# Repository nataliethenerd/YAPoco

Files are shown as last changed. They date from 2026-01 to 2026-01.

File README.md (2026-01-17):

# Yet Another Pocket Color (YAP)
mainimage

> Poco = Pocket Color. This project allows you to put a Game Boy Color in a Game Boy pocket shell. Full pocket colour PCB using the original parts. This board is made with modern screen kits in mind meaning it does not have the voltage rails for the original screen.

**ORDER AT 1MM WITH ENIG**

You can support me on Ko-Fi or by buying the board directly from me [my store](https://nataliethenerd.com/collections/all)

I also occasionally sell pre built PCBs on my store.



## Building

boardview

> [!WARNING]
> I am not responsible for your skill issues!

This board uses all the parts of an original Game Boy Color minus the IR and original screen circuit. Most parts are in the same spot, however if you are having trouble you can check the [interactive BOM](https://nataliethenerd.github.io/yap.html)

The thumbwheel circuit can be connected to an OSD screen to control brightness. The two touch pad wires and be conneced to the pads labelled ↑↓ on the back top left side of the board. The select, A and B pads are easy connection pads for the screen also. 

screenguide

**My recommendations** 

- New power regulator like my [Safer Charge DC](https://nataliethenerd.com/products/safer-charge-dc)
- [Q5 OSD Game Boy Color screen](https://s.click.aliexpress.com/e/_DmvDS95). The OSD allows you to move the screen
- Funny Playing Game Boy Pocket shell, with this shell you wont need to perform any trims.

**New parts**

- [Thumbwheel](https://s.click.aliexpress.com/e/_DFcsKf1)

## Update log:

Feb25: added pinouts for battery and 5V for testing and also my Safer Charger battery indicator LED board. Fixed some shielding pins, tied them to ground.

Jan26: changed the CPU footprint to be a bit more forgiving

| Before | After |
| --- | ----- |
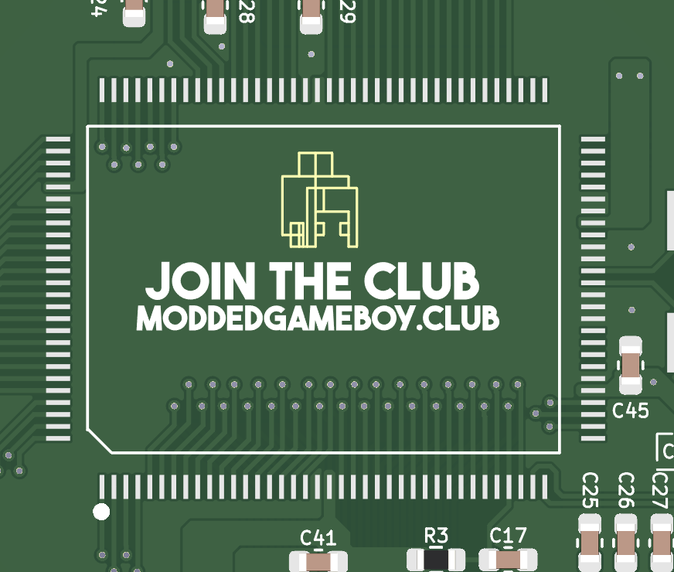
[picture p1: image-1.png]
old footprint
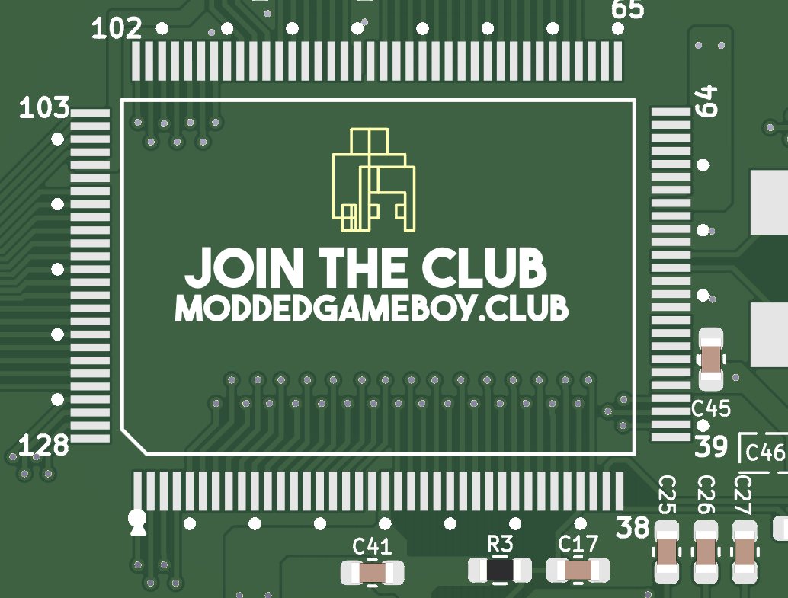
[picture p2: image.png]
new footprint
| |  |

## Thanks
- Hozy for the original Pocket Color concept
- Console and Casks for the thumbwheel circuit

## Follow me

If you are into Game Boy modding or retro gaming, please consider using code "NatalieTheNerd" at:

• [Retro Modding](http://RetroModding.com) 

• [Retro Game Repair Shop](http://RetroGameRepairShop.com) 

• [Extreme Rate](http://ExtremeRate.com)

**My socials**

• [Twitter](https://twitter.com/natalie_thenerd) 

• [Instagram](https://www.instagram.com/natalie.thenerd/) 

• [Modded Gameboy Club](https://moddedgameboy.club/) - a club dedicated to the modification of Game Boys, freely sharing resources

## License

Please do not remove my logo, website and name.



The CC BY-SA 4.0 (Creative Commons Attribution-ShareAlike 4.0 International) license allows you to:

1. **Share** - Copy and redistribute the material in any medium or format.
2. **Adapt** - Remix, transform, and build upon the material for any purpose, even commercially.

### Conditions:

- **Attribution** - You must give appropriate credit, provide a link to the license, and indicate if changes were made. You may do so in any reasonable manner, but not in any way that suggests the licensor endorses you or your use.
- **ShareAlike** - If you remix, transform, or build upon the material, you must distribute your contributions under the same license as the original.

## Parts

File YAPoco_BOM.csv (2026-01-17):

Reference | Value | Footprint | Qty | DNP
BT1 | Battery | CGB:Battery CGB | 1
C1 | 18pF | Capacitor_SMD:C_0603_1608Metric | 1
C2,C48,C49 | 27pF | Capacitor_SMD:C_0603_1608Metric,Resistor_SMD:R_0603_1608Metric | 3
C4 | 22pF | Capacitor_SMD:C_0603_1608Metric | 1
C5,C6,C7 | 100pF | Capacitor_SMD:C_0603_1608Metric | 3
C9,C10,C13,C29,C33,C41,C45 | 10nF | Capacitor_SMD:C_0603_1608Metric | 7
C14,C15,C16 | 47nF | Capacitor_SMD:C_0603_1608Metric | 3
C17,C18,C19,C25,C26,C27,C39 | 1uF | Capacitor_SMD:C_0603_1608Metric | 7
C24,C28,C40,C43,C44 | 100nF | Capacitor_SMD:C_0603_1608Metric | 5
C31 | 4.7uF | Capacitor_SMD:C_0603_1608Metric | 1
C32,C38 | 100uF | Capacitor_SMD:CP_Elec_5x5.3,Capacitor_SMD:CP_Elec_6.3x5.4 | 2
C46 | DNP | Capacitor_SMD:C_0603_1608Metric | 1 | DNP
C47 | 150pF | Capacitor_SMD:C_0603_1608Metric | 1
D2,D5 | 1SS355 | Diode_SMD:D_SOD-323_HandSoldering | 2
D4 | RED | LED_THT:LED_D3.0mm | 1
EM1,EM2,EM3,EM4,EM5,EM9 | BLM11B102S | Resistor_SMD:R_0603_1608Metric | 6
EM6,EM7,EM8 | BLM21PG221SG | Resistor_SMD:R_0805_2012Metric | 3
EM10 | ACM4532-801-2P | Crystal:Crystal_SMD_EuroQuartz_MJ-4Pin_5.0x3.2mm | 1
F1,F2 | ICP-S1.0TN | Fuse:Fuse_1206_3216Metric_Pad1.42x1.75mm_HandSolder | 2
FB1 | 4W601 | Resistor_SMD:R_Array_Concave_4x0603 | 1
J1 | Thumbwheel Toggle Switch | customsym:NAV_SWITCH | 1
P1 | Cart Connector | CGB:Cart CGB | 1
P2 | FPC 50 Pin 0.5 Pitch (top contacts) | CGB:Screen CGB | 1
P3 | Serial Port | CGB:Serial CGB | 1
P4,SW1,U7 | ~ | CGB:Switch CGB,POCO:DCJACK,Package_TO_SOT_SMD:SOT-23-5 | 3
P5 | Headphone Jack | POCO:HPjack | 1
Q2 | 2SC4081 | Package_TO_SOT_SMD:SOT-323_SC-70 | 1
R1,R7 | 750 | Resistor_SMD:R_0603_1608Metric | 2
R3 | 18K | Resistor_SMD:R_0603_1608Metric | 1
R8 | 47K | Resistor_SMD:R_0603_1608Metric | 1
R25 | 1.5M | Resistor_SMD:R_0603_1608Metric | 1
R26 | 5.6K | Resistor_SMD:R_0603_1608Metric | 1
R27 | 100R | Resistor_SMD:R_0603_1608Metric | 1
RA1 | 510R | Resistor_SMD:R_Array_Concave_2x0603 | 1
RA2 | 15R | Resistor_SMD:R_Array_Concave_2x0603 | 1
RA3 | 270R | Resistor_SMD:R_Array_Concave_4x0603 | 1
SP1 | Speaker | TestPoint:TestPoint_2Pads_Pitch2.54mm_Drill0.8mm | 1
SW2 | Right | CGB:Dpad CGB | 1
SW3 | Down | CGB:Dpad CGB | 1
SW4 | Up | CGB:Dpad CGB | 1
SW5 | Left | CGB:Dpad CGB | 1
SW6 | A | CGB:AB CGB | 1
SW7 | B | CGB:AB CGB | 1
SW8 | Select | CGB:Select CGB | 1
SW9 | Start | CGB:Start CGB | 1
TST3 | TestPoint |  | 1
U1 | CGB CPU | CGB:CPU CGB | 1
U2 | CGB SRAM | Package_SO:TSOP-I-28_11.8x8mm_P0.55mm | 1
U3 | MGB AMP | CGB:Amp MGB | 1
U5 | DC-DC | POCO:DC | 1
U6 | PST9135N | Package_TO_SOT_SMD:SOT-23-5 | 1
VR1 | 10K Dual Thumbwheel Potentiometer | CGB:Volume wheel CGB | 1
X1 | 8.388608MHZ | CGB:Crystal CGB | 1

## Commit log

2024-07-12 kicad files
    [CGB_Serial.kicad_sch, CGB_Sound.kicad_sch, YAPoco.kicad_pcb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]
2024-07-14 updated some labels
    [YAPoco.kicad_pcb, YAPoco.kicad_sch, cgb_controls.kicad_sch]
2025-02-23 feb25 update
    [YAPoco.kicad_pcb, bom.csv, designators.csv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]
2026-01-01 changed cpu footprint
    [YAPoco.kicad_pcb]
2026-01-17 fixed some BOM stuff
    [CGB_Serial.kicad_sch, CGB_Sound.kicad_sch, YAPoco.kicad_pcb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]
